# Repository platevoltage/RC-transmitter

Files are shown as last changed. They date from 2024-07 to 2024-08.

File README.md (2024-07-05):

MAKE_PIN(P0, 0);   // General I/O pin, mapped to GPIO21
MAKE_PIN(P1, 1);    // TX0, typically GPIO1 for UART0 TX
MAKE_PIN(P10, 10);  // TX1, mapped to GPIO17 for UART1 TX
MAKE_PIN(P3, 3);    // RX0, typically GPIO3 for UART0 RX
MAKE_PIN(P21, 21);   // SDA, typically GPIO8 for I2C SDA
MAKE_PIN(P22, 22);   // SCL, typically GPIO9 for I2C SCL
MAKE_PIN(P19, 9);  // MISO, typically GPIO12 for SPI MISO
MAKE_PIN(P23, 11);  // MOSI, typically GPIO13 for SPI MOSI
MAKE_PIN(P18, 7);  // SCK, typically GPIO14 for SPI SCK
MAKE_PIN(P5, 12);   // SS, typically GPIO15 for SPI SS
MAKE_PIN(P17, 5);   // INT, using GPIO4 for interrupt

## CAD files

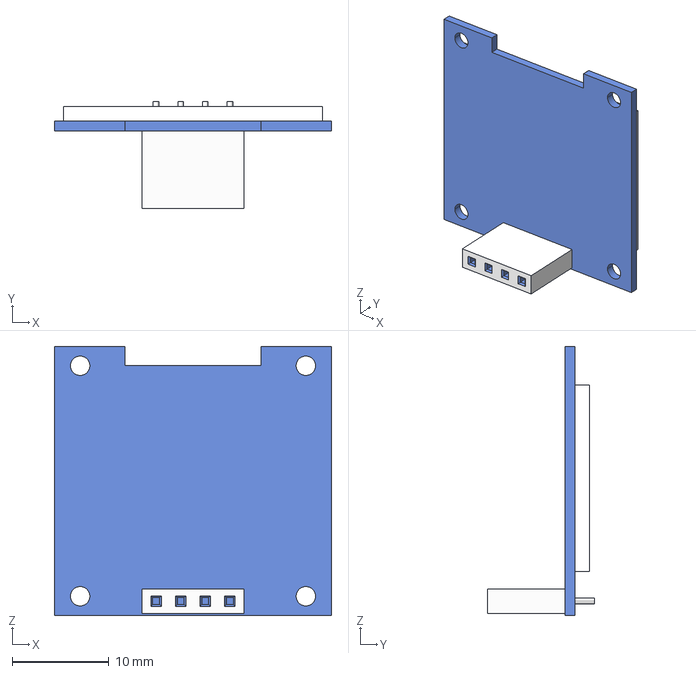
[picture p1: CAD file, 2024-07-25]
PCB/3D_RAK1921.stp
28.6 x 11.0 x 27.8 mm

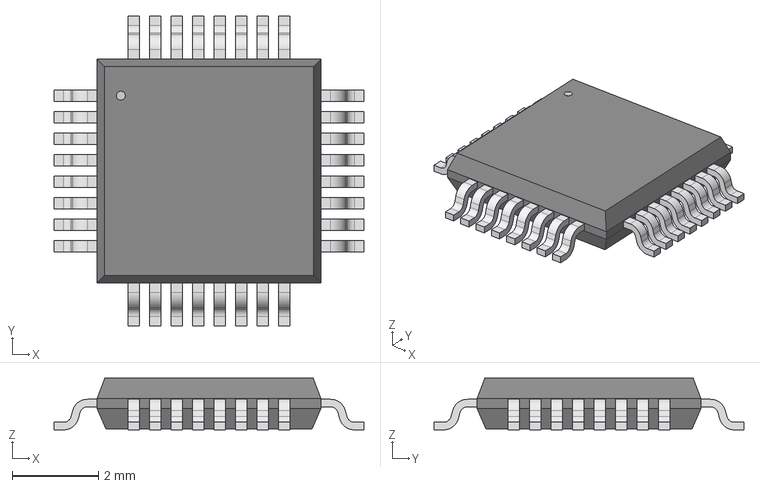
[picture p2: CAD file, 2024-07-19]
PCB/MAX3421EEHJ_T-2/21-0110-C_90-0149-32L_MXM.step
7.20 x 7.20 x 1.20 mm

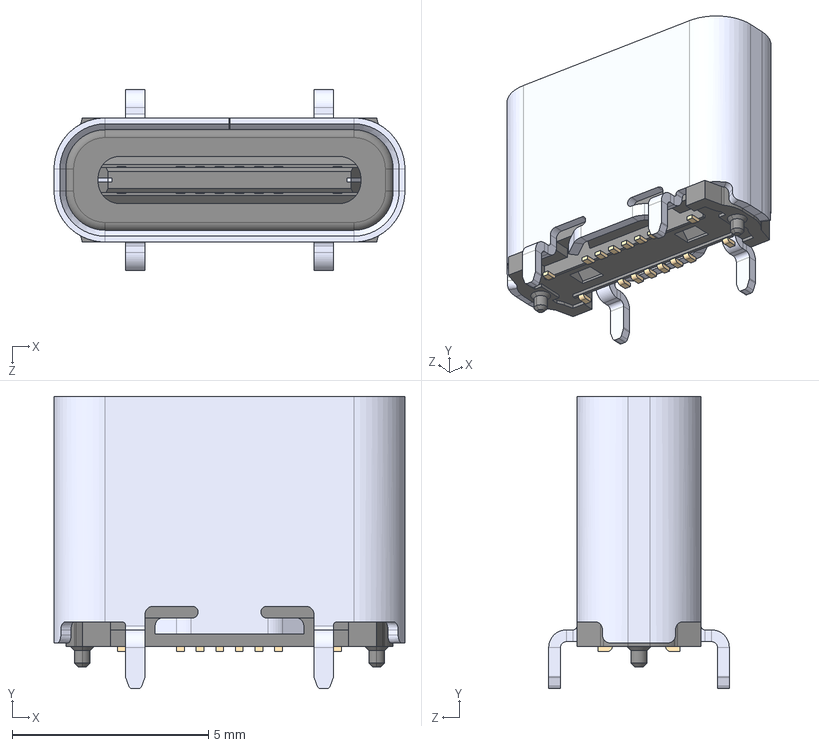
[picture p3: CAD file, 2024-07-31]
PCB/USB4120_03_C/USB4120-03-C_REVA.step
8.94 x 7.45 x 4.60 mm

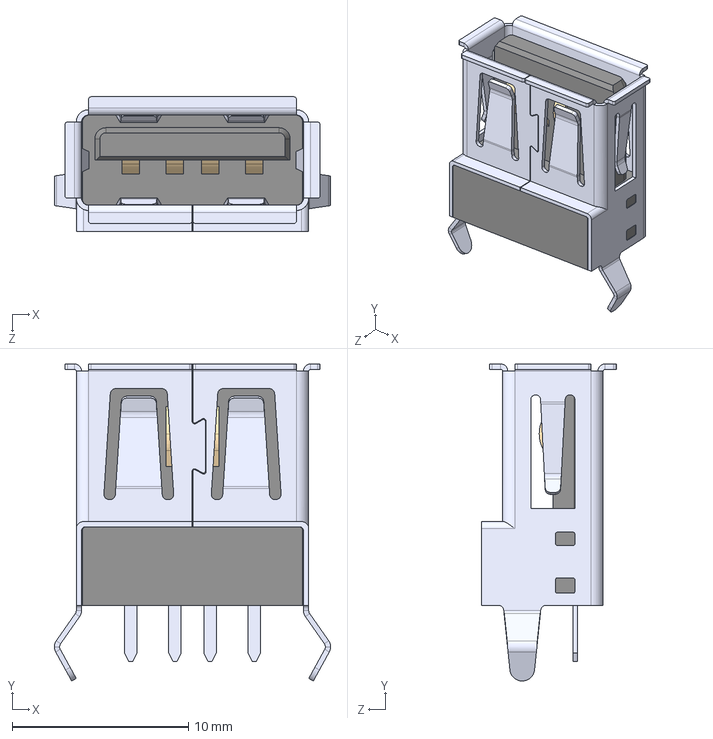
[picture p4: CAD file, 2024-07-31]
PCB/USB_A1VSB6/USB-A1VSB6.step
15.7 x 18.0 x 7.64 mm

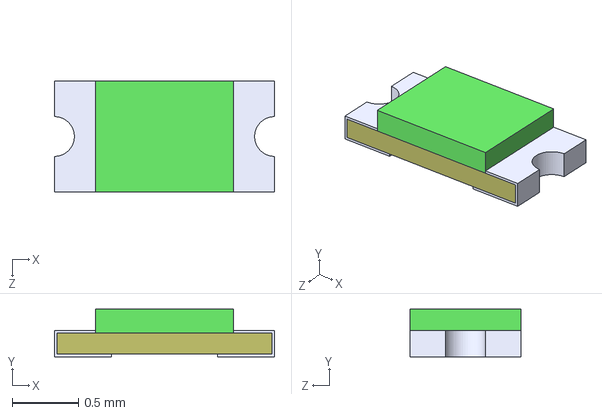
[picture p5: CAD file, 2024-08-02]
PCB/PGB1010603MR/PGB1010603MR.step
1.66 x 0.36 x 0.84 mm

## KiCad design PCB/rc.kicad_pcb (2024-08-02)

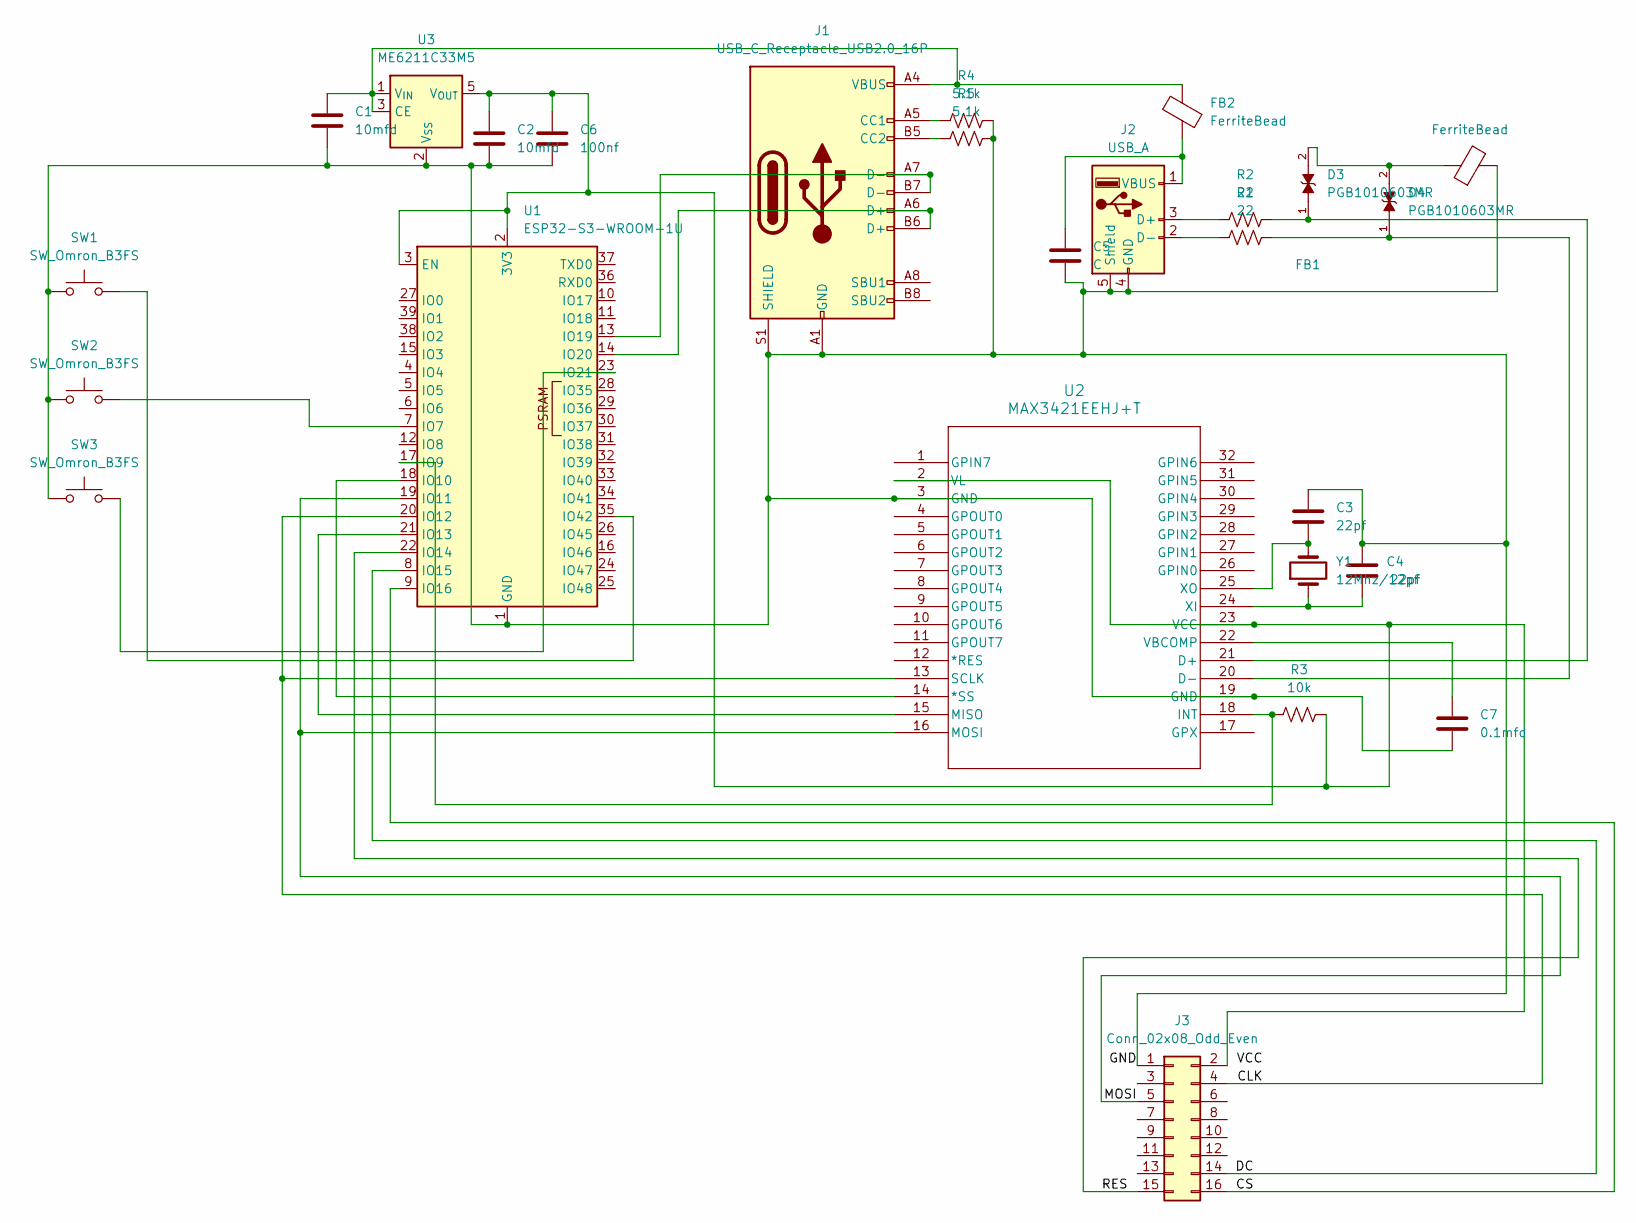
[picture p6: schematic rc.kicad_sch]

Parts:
C1, C2: 10mfd; C_0402_1005Metric_Pad0.74x0.62mm_HandSolder
C3, C4: 22pf; C_0402_1005Metric_Pad0.74x0.62mm_HandSolder
C5: C; C_0402_1005Metric_Pad0.74x0.62mm_HandSolder
C6: 100nf; C_0402_1005Metric_Pad0.74x0.62mm_HandSolder
C7: 0.1mfd; C_0402_1005Metric_Pad0.74x0.62mm_HandSolder
D3, D4: PGB1010603MR; DIOC1608X36N; PARTREV 07/27/15
FB1, FB2: FerriteBead; L_0603_1608Metric
J1: USB_C_Receptacle_USB2.0_16P; GCT_USB4120-03-C_REVA
J2: USB_A; ONSHORE_USB-A1VSB6
J3: Conn_02x08_Odd_Even; PinSocket_2x08_P2.54mm_Vertical
R1, R2: 22; R_0402_1005Metric_Pad0.72x0.64mm_HandSolder
R3: 10k; R_0402_1005Metric_Pad0.72x0.64mm_HandSolder
R4, R5: 5.1k; R_0402_1005Metric_Pad0.72x0.64mm_HandSolder
SW1, SW2, SW3: SW_Omron_B3FS; SW_SPST_Omron_B3FS-105xP
U1: ESP32-S3-WROOM-1U
U2: MAX3421EEHJ+T; 21-0110-C_90-0149-32L_MXM
U3: ME6211C33M5; SOT-23-5
Y1: 12Mhz/12pf; Crystal_SMD_G8-2Pin_3.2x1.5mm

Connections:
/CLK: J3.4, U1.20 (IO12), U2.13 (SCLK)
/CS: J3.16, U1.9 (IO16)
/DC: J3.14, U1.8 (IO15)
/GND: C1.2, C2.2, C3.1, C4.1, C5.2, C6.2, C7.2, FB1.2, J1.A1 (GND), J1.A12 (GND), J1.B1 (GND), J1.B12 (GND), J1.S1 (SHIELD), J2.4 (GND), J2.5 (Shield), J3.1, R4.2, R5.2, SW1.1, SW2.1, SW3.1, U1.1 (GND), U1.40 (GND), U1.41 (GND), U2.3 (GND), U2.19 (GND), U3.2 (V_{SS})
/MOSI: J3.5, U1.19 (IO11), U2.16 (MOSI)
/RES: J3.15, U1.22 (IO14)
unnamed: D3.2, D4.2, FB1.1
unnamed: J1.A5 (CC1), R4.1
unnamed: J1.B5 (CC2), R5.1
unnamed: J2.3 (D+), R2.1
unnamed: J2.2 (D-), R1.1
unnamed: C5.1, FB2.1, J2.1 (VBUS)
unnamed: C2.1, C6.1, J3.2, R3.2, U1.2 (3V3), U1.3 (EN), U2.2 (VL), U2.23 (VCC), U3.5 (V_{OUT})
unnamed: SW2.2, U1.7 (IO7)
unnamed: R3.1, U1.17 (IO9), U2.18 (INT)
unnamed: U1.18 (IO10), U2.14 (*SS)
unnamed: U1.21 (IO13), U2.15 (MISO)
unnamed: J1.A7 (D-), J1.B7 (D-), U1.13 (IO19)
unnamed: J1.A6 (D+), J1.B6 (D+), U1.14 (IO20)
unnamed: SW3.2, U1.23 (IO21)
unnamed: SW1.2, U1.35 (IO42)
unnamed: D3.1, R2.2, U2.21 (D+)
unnamed: D4.1, R1.2, U2.20 (D-)
unnamed: C7.1, U2.22 (VBCOMP)
unnamed: C4.2, U2.24 (XI), Y1.1
unnamed: C3.2, U2.25 (XO), Y1.2
unnamed: C1.1, FB2.2, J1.A4 (VBUS), J1.A9 (VBUS), J1.B4 (VBUS), J1.B9 (VBUS), U3.1 (V_{IN}), U3.3 (CE)

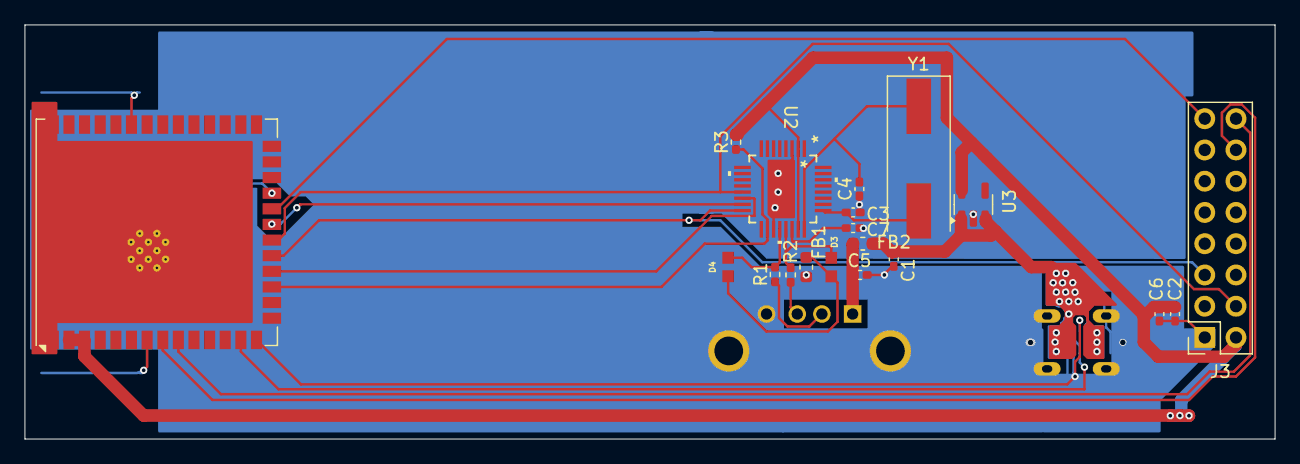
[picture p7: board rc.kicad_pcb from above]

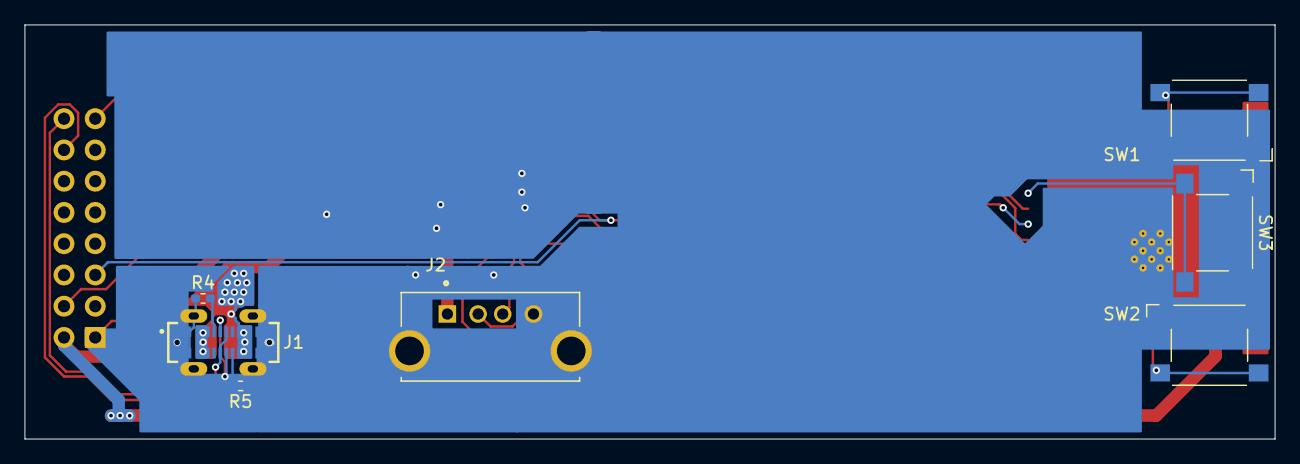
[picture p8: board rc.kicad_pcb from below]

Board: 2 copper layers, 101.6 x 33.7 mm, 26 parts (7 on the bottom side), 27 nets.

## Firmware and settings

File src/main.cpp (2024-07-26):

#include "Transmitter.h"
#include <usbhid.h>
#include <hiduniversal.h>
#include <usbhub.h>
#include <SPI.h>
#include <U8g2lib.h>
#include "hidjoystickrptparser.h"

uint8_t receiverMacAddress[] = {0x84, 0xF7, 0x03, 0xF1, 0x1E, 0xDC};
// struct_message messageData;
Transmitter transmitter;
USB Usb;
USBHub Hub(&Usb);
HIDUniversal Hid(&Usb);
JoystickEvents JoyEvents;
JoystickReportParser Joy(&JoyEvents);
U8G2_SSD1322_NHD_256X64_F_4W_HW_SPI u8g2(U8G2_R0, /* cs=*/ 39, /* dc=*/ 37, /* reset=*/ 35);

// bool up;
// bool down;
// bool left;
// bool right;

// bool A;
// bool B;
// bool X;
// bool Y;

void setup() {
    u8g2.begin();
    // Initialize Serial Monitor
    Serial.begin(115200);
    // pinMode(18, INPUT_PULLUP);
    // delay(3000);
    transmitter.init(receiverMacAddress);

    Serial.println("start");
    int usbInitCode = Usb.Init();
    Serial.println(usbInitCode);
    if (usbInitCode == -1)
            Serial.println("OSC did not start.");

    // delay(2000);

    if (!Hid.SetReportParser(0, &Joy))
            ErrorMessage<uint8_t > (PSTR("SetReportParser"), 1);
    // delay(1000);
}



void loop() {
    Usb.Task();

    struct_message message = JoyEvents.getParsedHIDReport();

    transmitter.sendData(message);
    u8g2.clearBuffer();
    u8g2.setFont(u8g2_font_helvB12_tr);
    String steer = "Steer: ";
    steer.concat(message.steering);
    u8g2.drawStr(0,14, steer.c_str());
    String drive = "Drive: ";
    drive.concat(message.drive);
    u8g2.drawStr(0,28, drive.c_str());

    // String usbStatus = "";
    // usbStatus.concat(Usb.getUsbTaskState());
    // u8g2.drawStr(0,42, usbStatus.c_str());
    String upStatus = "";
    upStatus.concat(JoyEvents.up);
    u8g2.drawStr(10,42, upStatus.c_str());
    String leftStatus = "";
    leftStatus.concat(JoyEvents.left);
    u8g2.drawStr(0,52, leftStatus.c_str());
    String rightStatus = "";
    rightStatus.concat(JoyEvents.right);
    u8g2.drawStr(20,52, rightStatus.c_str());
    String downStatus = "";
    downStatus.concat(JoyEvents.down);
    u8g2.drawStr(10,60, downStatus.c_str());

    String YStatus = "";
    YStatus.concat(JoyEvents.Y);
    u8g2.drawStr(50,42, YStatus.c_str());
    String XStatus = "";
    XStatus.concat(JoyEvents.X);
    u8g2.drawStr(40,52, XStatus.c_str());
    String BStatus = "";
    BStatus.concat(JoyEvents.B);
    u8g2.drawStr(60,52, BStatus.c_str());
    String AStatus = "";
    AStatus.concat(JoyEvents.A);
    u8g2.drawStr(50,60, AStatus.c_str());

    String reverseStatus = "";
    reverseStatus.concat(JoyEvents.reverse);
    u8g2.drawStr(80,52, reverseStatus.c_str());

    String startStatus = "";
    startStatus.concat(JoyEvents.start);
    u8g2.drawStr(92,52, startStatus.c_str());

    if (Usb.getUsbTaskState() != 144) {

      
        u8g2.setDrawColor(0);
        u8g2.drawBox(0,0,128,64);
        u8g2.setDrawColor(1);

        
        // u8g2.drawBox(0,18,124,30);
        // u8g2.drawFrame(0,18,124,30);
        // u8g2.setDrawColor(0);
        // u8g2.drawBox(4,22,124,32);
        // u8g2.setDrawColor(1);
        // u8g2.drawFrame(4,22,124,32);
        u8g2.setFont(u8g2_font_helvB10_tr);
        // u8g2.drawStr(8,42, "Connect Wheel!");
        u8g2.drawButtonUTF8(62, 30, U8G2_BTN_SHADOW1|U8G2_BTN_HCENTER|U8G2_BTN_BW2, 34,  2,  2, "Connect Wheel!" );
        u8g2.drawStr(60,52, String(Usb.getUsbTaskState()).c_str());

    }
    u8g2.sendBuffer();
    // delay(1000);  
    Serial.println(esp_get_free_heap_size());
}

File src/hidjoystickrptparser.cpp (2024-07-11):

#include "hidjoystickrptparser.h"


JoystickReportParser::JoystickReportParser(JoystickEvents *evt) :
joyEvents(evt),
oldAccelerator(0xDE),
oldStandardButtons(0) {
        for (uint8_t i = 0; i < RPT_GEMEPAD_LEN; i++)
                oldPad[i] = 0xD;
}

struct_message messageData;

void JoystickReportParser::Parse(USBHID *hid, bool is_rpt_id, uint8_t len, uint8_t *buf) {

        bool match = true;
        
        // for (uint8_t i = 0; i < RPT_GEMEPAD_LEN; i++) {
        //         Serial.print("0x");
        //         if (buf[i] < 16) {
        //                 Serial.print("0"); // Add leading zero if value is less than 16
        //         }
        //         Serial.print(buf[i], HEX);
        //         Serial.print("  ");
        // }
        // Serial.println();

        for (uint8_t i = 0; i < RPT_GEMEPAD_LEN; i++) {
        // Checking if there are changes in report since the method was last called
                if (buf[i] != oldPad[i]) {
                        match = false;
                        break;
                }
        }

        // Calling Game Pad event handler
        if (!match && joyEvents) {
                //PRINTS VALUES
                // joyEvents->OnGamePadChanged((const GamePadEventData*)buf);

                for (uint8_t i = 0; i < RPT_GEMEPAD_LEN; i++) oldPad[i] = buf[i];
        }

        uint8_t accelerator = (buf[6]);
        if (accelerator != oldAccelerator && joyEvents) {
                // Serial.println(buf[5], HEX);
                joyEvents->OnAcceleratorChange(accelerator);
                oldAccelerator = accelerator;
        }

        uint8_t brake = (buf[12]);
        if (brake != oldBrake && joyEvents) {
                joyEvents->OnBrakeChange(brake);
                oldBrake = brake;
        }

        uint8_t wheel = (buf[2]);
        if (wheel != oldWheel && joyEvents) {
                joyEvents->OnWheelChange(wheel);
                oldWheel = wheel;
        }

        uint16_t standardButtons = (0x0000 | buf[18]);
        standardButtons <<= 4;
        standardButtons |= (buf[17] >> 4);
        uint16_t standardChanges = (standardButtons ^ oldStandardButtons);

        // Calling Button Event Handler for every button changed
        if (standardChanges) {
                for (uint8_t i = 0; i < 0x0C; i++) {
                        uint16_t mask = (0x0001 << i);

                        if (((mask & standardChanges) > 0) && joyEvents) {
                                if ((standardButtons & mask) > 0)
                                        joyEvents->OnButtonDn(i + 1);
                                else
                                        joyEvents->OnButtonUp(i + 1);
                        }
                }
                oldStandardButtons = standardButtons;
        }


        uint16_t rightButtons = (0x0000 | buf[22]);
        rightButtons <<= 4;
        rightButtons |= (buf[21] >> 4);
        uint16_t rightChanges = (rightButtons ^ oldRightButtons);

        // Calling Button Event Handler for every button changed
        if (rightChanges) {
                for (uint8_t i = 0; i < 0x0C; i++) {
                        uint16_t mask = (0x0001 << i);

                        if (((mask & rightChanges) > 0) && joyEvents) {
                                if ((rightButtons & mask) > 0)
                                        joyEvents->OnRightButtonDn(i + 1);
                                else
                                        joyEvents->OnRightButtonUp(i + 1);
                        }
                }
                oldRightButtons = rightButtons;
        }
}

void JoystickEvents::OnGamePadChanged(const GamePadEventData *evt) {
        Serial.print("A: ");
        PrintHex<uint8_t > (evt->A, 0x80);
        Serial.print("\tB: ");
        PrintHex<uint8_t > (evt->B, 0x80);
        Serial.print("\tC: ");
        PrintHex<uint8_t > (evt->C, 0x80);
        Serial.print("\tD: ");
        PrintHex<uint8_t > (evt->D, 0x80);
        Serial.print("\tE: ");
        PrintHex<uint8_t > (evt->E, 0x80);
        Serial.print("\tF: ");
        PrintHex<uint8_t > (evt->F, 0x80);
        Serial.print("\tG: ");
        PrintHex<uint8_t > (evt->G, 0x80);
        Serial.print("\tH: ");
        PrintHex<uint8_t > (evt->H, 0x80);
        Serial.print("\tI: ");
        PrintHex<uint8_t > (evt->I, 0x80);
        Serial.print("\tJ: ");
        PrintHex<uint8_t > (evt->J, 0x80);
        Serial.print("\tK: ");
        PrintHex<uint8_t > (evt->K, 0x80);
        Serial.print("\tL: ");
        PrintHex<uint8_t > (evt->L, 0x80);
        Serial.print("\tM: ");
        PrintHex<uint8_t > (evt->M, 0x80);
        Serial.print("\tN: ");
        PrintHex<uint8_t > (evt->N, 0x80);
        Serial.print("\tO: ");
        PrintHex<uint8_t > (evt->O, 0x80);
        Serial.print("\tP: ");
        PrintHex<uint8_t > (evt->P, 0x80);
        Serial.print("\tQ: ");
        PrintHex<uint8_t > (evt->Q, 0x80);
        Serial.print("\tR: ");
        PrintHex<uint8_t > (evt->R, 0x80);
        Serial.print("\tS: ");
        PrintHex<uint8_t > (evt->S, 0x80);
        Serial.print("\tT: ");
        PrintHex<uint8_t > (evt->T, 0x80);
        Serial.print("\tU: ");
        PrintHex<uint8_t > (evt->U, 0x80);
        Serial.print("\tV: ");
        PrintHex<uint8_t > (evt->V, 0x80);
        Serial.print("\tW: ");
        PrintHex<uint8_t > (evt->W, 0x80);
        Serial.print("\tX: ");
        PrintHex<uint8_t > (evt->X, 0x80);
        Serial.println("");
}

void JoystickEvents::OnHatSwitch(uint8_t hat) {
        // Serial.print("Hat Switch: ");
        // PrintHex<uint8_t > (hat, 0x80);
        // Serial.println("");
}

void JoystickEvents::OnButtonUp(uint8_t but_id) {
        Serial.print("Up: ");
        Serial.println(but_id, DEC);
        switch (but_id) {
                case 1: A = false; break;
                case 2: B = false; break;
                case 3: X = false; break;
                case 4: Y = false; break;
                case 5: up = false; break;
                case 6: right = false; break;
                case 7: down = false; break;
                case 8: left = false; break;
        }
}

void JoystickEvents::OnButtonDn(uint8_t but_id) {
        Serial.print("Dn: ");
        Serial.println(but_id, DEC);
        switch (but_id) {
                case 1: A = true; break;
                case 2: B = true; break;
                case 3: X = true; break;
                case 4: Y = true; break;
                case 5: up = true; break;
                case 6: right = true; break;
                case 7: down = true; break;
                case 8: left = true; break;
        }
}
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

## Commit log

2024-07-10 parsed reverse button
2024-07-10 start button
2024-07-19 pcb init
    [21-0110-C_90-0149-32L_MXM.step, rc.kicad_pcb, rc.kicad_sch]
2024-07-25 pcb update
    [3D_RAK1921.stp, rc.kicad_pcb, rc.kicad_sch]
2024-07-31 3 inch display
    [USB-A1VSB6.step, USB4120-03-C_REVA.step, rc.kicad_pcb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]
2024-08-02 more board
    [PGB1010603MR.step, rc.kicad_pcb, rc.kicad_sch]
